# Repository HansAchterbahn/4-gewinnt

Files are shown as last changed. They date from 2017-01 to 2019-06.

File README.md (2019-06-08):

# 4 Gewinnt mit LED Matrix und Raspberry Pi

Das hier liegende Projekt ist ein 4 Gewinnt Spiel. Es funktioniert mit Raspberry Pi und einer LED Matrix. Eine genaue Beschreibung des Projekts findet ihr in dem Ordner *Dokumentaton* oder auf meinem Blog. 
Viel Spaß beim ausprobieren und erweitern!  

Blog:  
https://aetzenloetenprogrammieren.blogspot.de/2016/06/4-gewinnt-auf-led-matrix-mit-raspberry.html

Youtube Video: 4-Gewinnt auf LED-Matrix mit Raspberry Pi (http://www.youtube.com/watch?v=UU7TQ19X6Fk "4-Gewinnt auf LED-Matrix mit Raspberry Pi")

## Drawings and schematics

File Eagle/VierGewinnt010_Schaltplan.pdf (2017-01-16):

GND | GND | GND

# GND

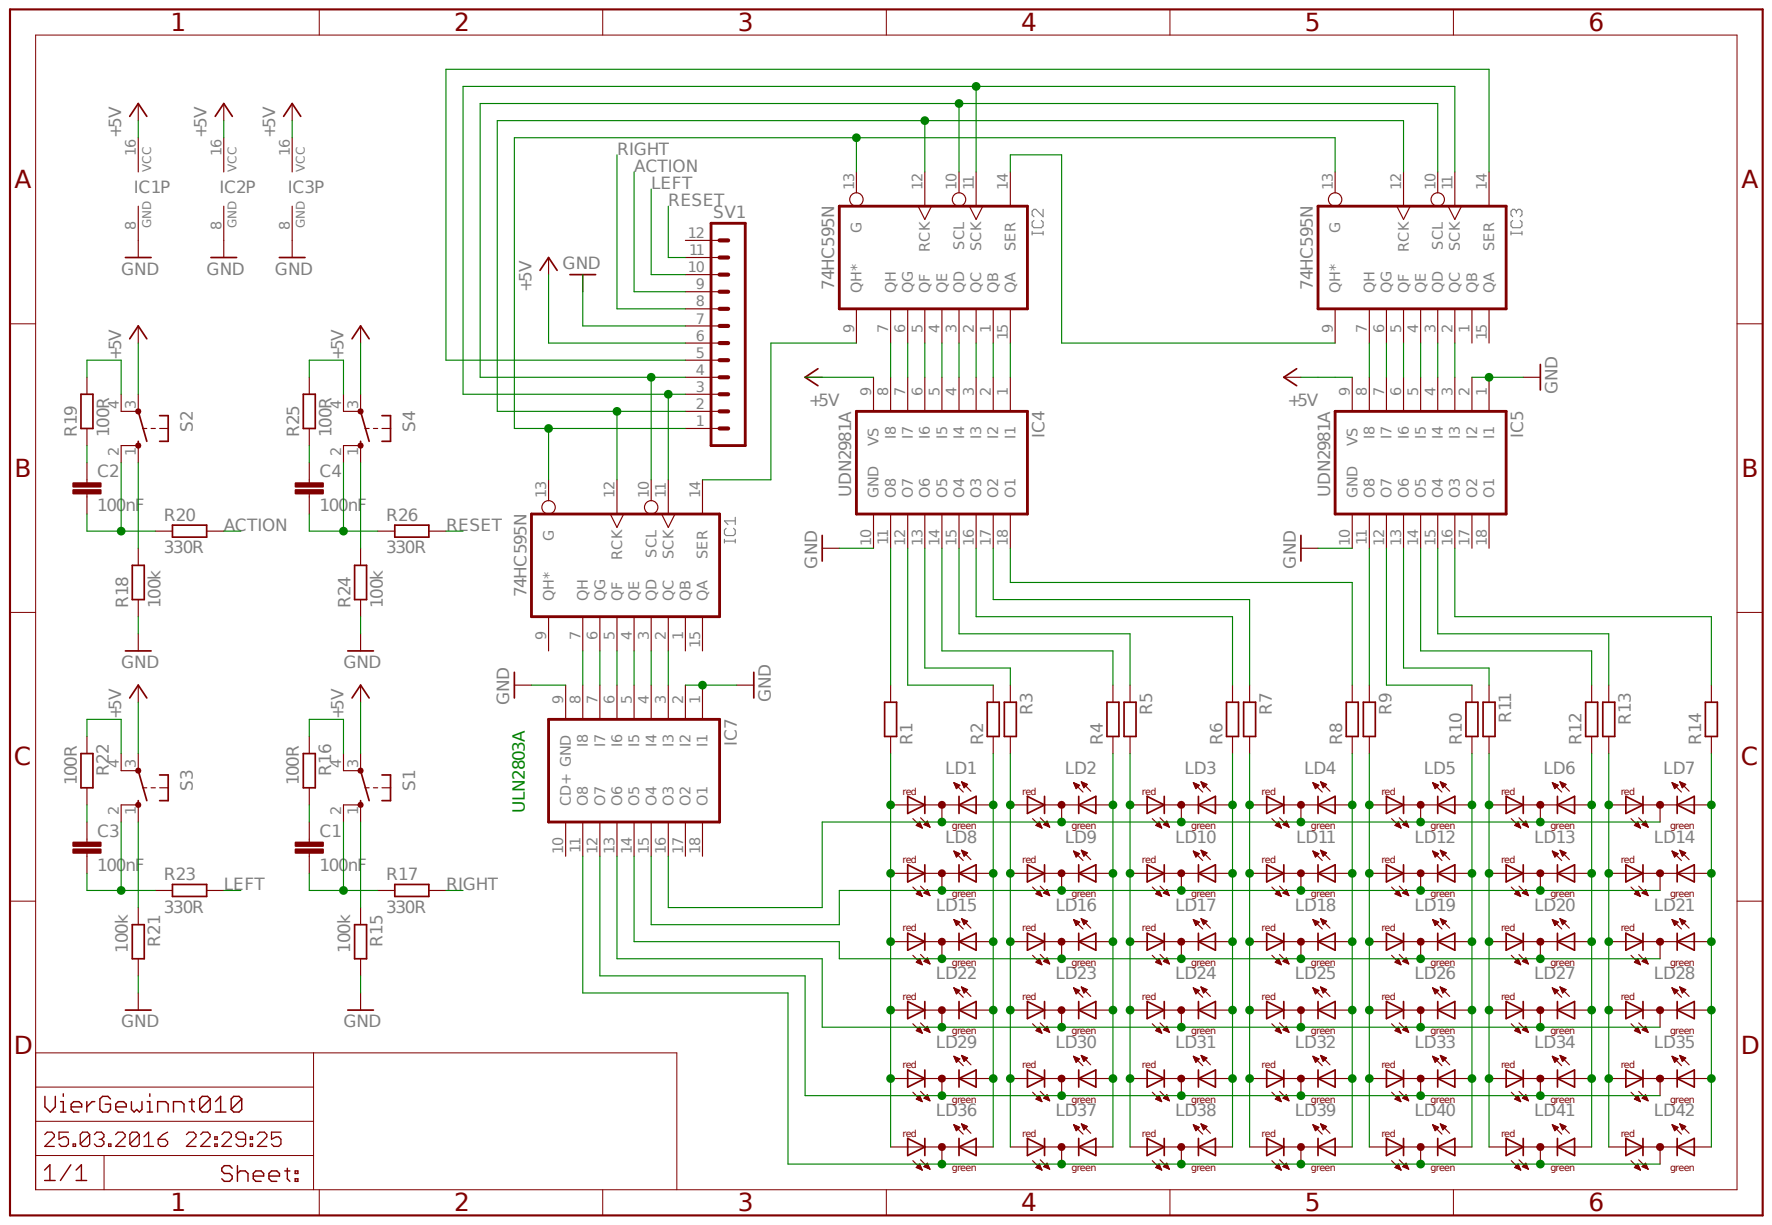
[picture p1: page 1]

QB 1 QC 2 QD 3 QE 4 QF 5 QG 6 QH 7 SCL 10 SCK 11 RCK 12

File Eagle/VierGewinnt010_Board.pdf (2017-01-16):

IC5

# IC7 UDN²⁹⁸¹A UDN²⁹⁸¹A

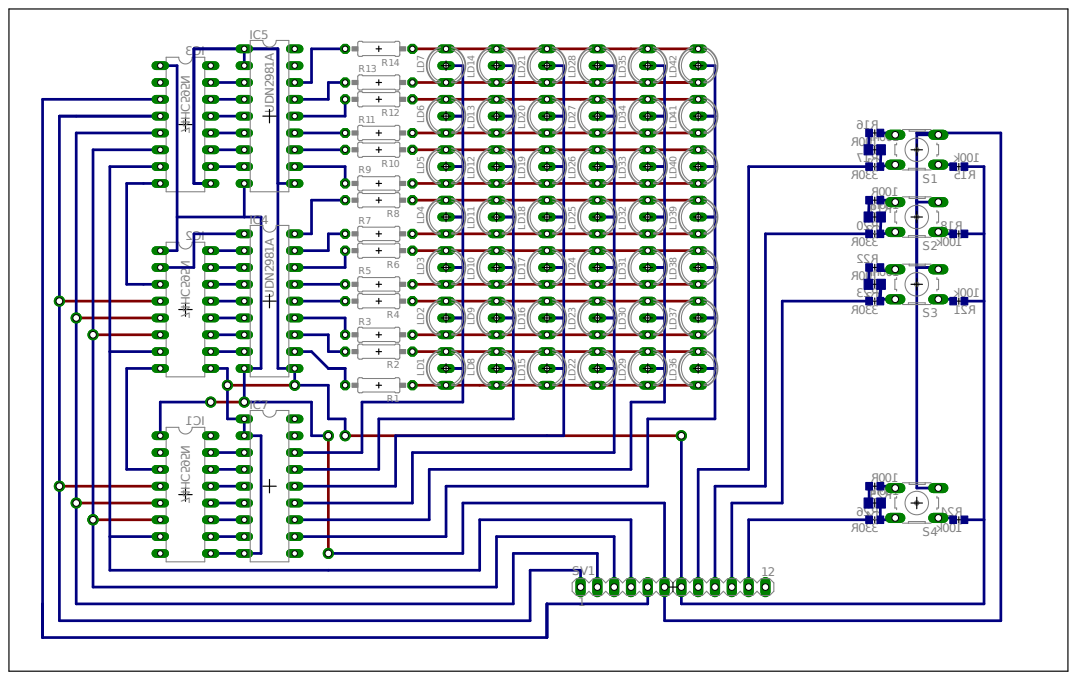
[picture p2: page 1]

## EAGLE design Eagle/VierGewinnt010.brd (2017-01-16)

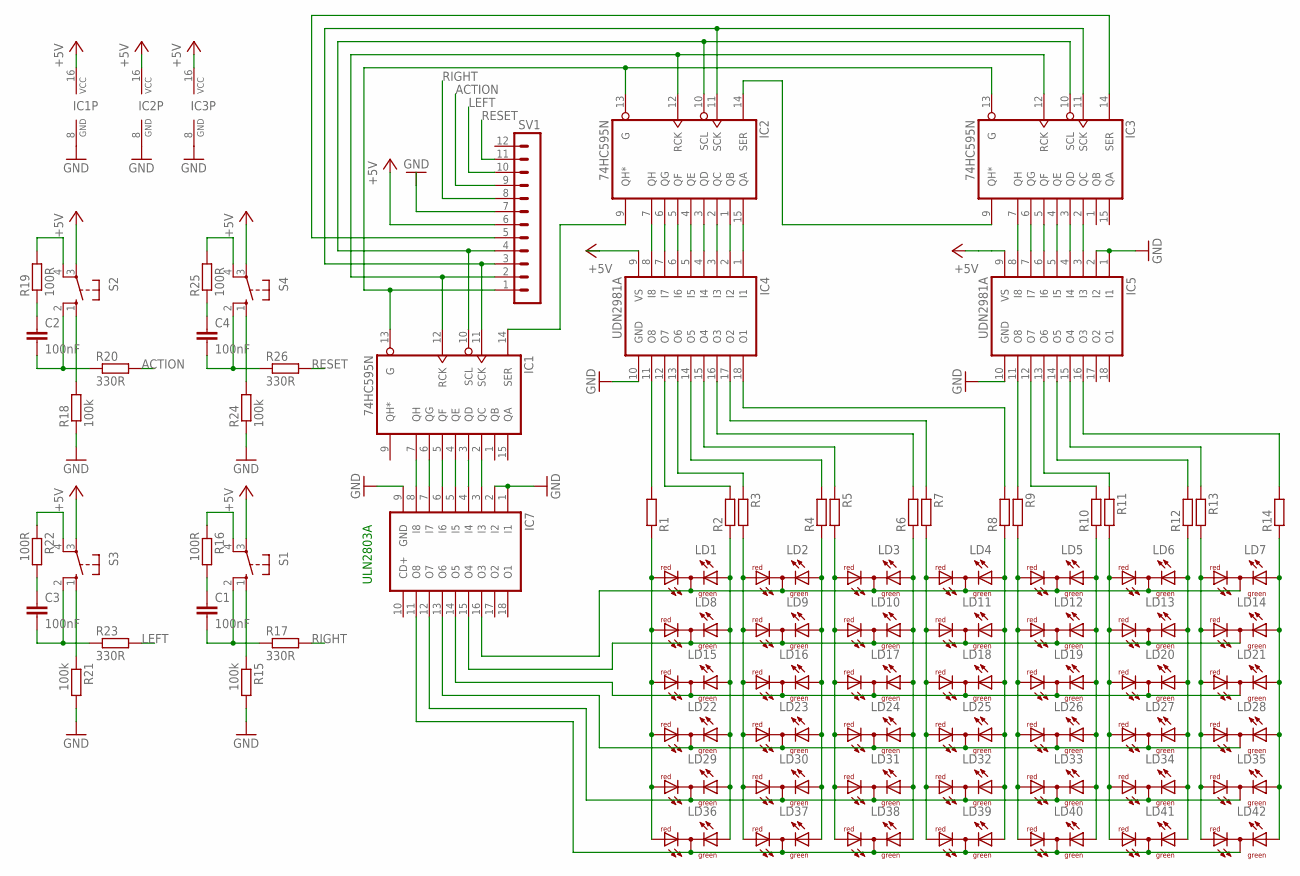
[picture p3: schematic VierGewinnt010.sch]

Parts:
C1, C2, C3, C4: 100nF; C0805
IC1, IC2, IC3: 74HC595N; DIL16
IC4, IC5: UDN2981A; DIL18
IC7: ULN2803A; DIL18
LD1, LD2, LD3, LD4, LD5, LD6, LD7, LD8, LD9, LD10, LD11, LD12, LD13, LD14, LD15, LD16, LD17, LD18, LD19, LD20, LD21, LD22, LD23, LD24, LD25, LD26, LD27, LD28, LD29, LD30, LD31, LD32, LD33, LD34, LD35, LD36, LD37, LD38, LD39, LD40, LD41, LD42: DUOLED-RG-C; DUOLED-C-5MM
R1, R2, R3, R4, R5, R6, R7, R8, R9, R10, R11, R12, R13, R14: R-EU_0207/10; 0207/10
R15, R18, R21, R24: 100k; R0603
R16, R19, R22, R25: 100R; R0603
R17, R20, R23, R26: 330R; R0603
S1, S2, S3, S4: 10-XX; B3F-10XX
SV1: MA12-1

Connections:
+5V: IC1.16 (VCC), IC2.16 (VCC), IC3.16 (VCC), IC4.9 (VS), IC5.9 (VS), S1.3, S2.3, S3.3, S4.3, SV1.6
ACTION: R20.2, SV1.9
GND: IC1.8 (GND), IC2.8 (GND), IC3.8 (GND), IC4.10 (GND), IC5.1 (I1), IC5.2 (I2), IC5.10 (GND), IC7.1 (I1), IC7.2 (I2), IC7.9 (GND), R15.2, R18.1, R21.2, R24.1, SV1.7
LEFT: R23.2, SV1.10
unnamed: LD1.AR, LD8.AR, LD15.AR, LD22.AR, LD29.AR, LD36.AR, R1.1
unnamed: LD1.AX (AG), LD8.AX (AG), LD15.AX (AG), LD22.AX (AG), LD29.AX (AG), LD36.AX (AG), R2.1
unnamed: LD2.AR, LD9.AR, LD16.AR, LD23.AR, LD30.AR, LD37.AR, R3.2
unnamed: LD2.AX (AG), LD9.AX (AG), LD16.AX (AG), LD23.AX (AG), LD30.AX (AG), LD37.AX (AG), R4.1
unnamed: LD3.AR, LD10.AR, LD17.AR, LD24.AR, LD31.AR, LD38.AR, R5.2
unnamed: LD3.AX (AG), LD10.AX (AG), LD17.AX (AG), LD24.AX (AG), LD31.AX (AG), LD38.AX (AG), R6.1
unnamed: LD4.AR, LD11.AR, LD18.AR, LD25.AR, LD32.AR, LD39.AR, R7.2
unnamed: LD4.AX (AG), LD11.AX (AG), LD18.AX (AG), LD25.AX (AG), LD32.AX (AG), LD39.AX (AG), R8.1
unnamed: LD5.AR, LD12.AR, LD19.AR, LD26.AR, LD33.AR, LD40.AR, R9.2
unnamed: LD5.AX (AG), LD12.AX (AG), LD19.AX (AG), LD26.AX (AG), LD33.AX (AG), LD40.AX (AG), R10.1
unnamed: LD6.AR, LD13.AR, LD20.AR, LD27.AR, LD34.AR, LD41.AR, R11.2
unnamed: LD6.AX (AG), LD13.AX (AG), LD20.AX (AG), LD27.AX (AG), LD34.AX (AG), LD41.AX (AG), R12.1
unnamed: LD7.AR, LD14.AR, LD21.AR, LD28.AR, LD35.AR, LD42.AR, R13.2
unnamed: LD7.AX (AG), LD14.AX (AG), LD21.AX (AG), LD28.AX (AG), LD35.AX (AG), LD42.AX (AG), R14.1
unnamed: IC7.16 (O3), LD1.C, LD2.C, LD3.C, LD4.C, LD5.C, LD6.C, LD7.C
unnamed: IC7.14 (O5), LD15.C, LD16.C, LD17.C, LD18.C, LD19.C, LD20.C, LD21.C
unnamed: IC7.13 (O6), LD22.C, LD23.C, LD24.C, LD25.C, LD26.C, LD27.C, LD28.C
unnamed: IC7.12 (O7), LD29.C, LD30.C, LD31.C, LD32.C, LD33.C, LD34.C, LD35.C
unnamed: IC7.11 (O8), LD36.C, LD37.C, LD38.C, LD39.C, LD40.C, LD41.C, LD42.C
unnamed: IC4.11 (O8), R1.2
unnamed: IC4.12 (O7), R2.2
unnamed: IC4.13 (O6), R3.1
unnamed: IC4.14 (O5), R4.2
unnamed: IC4.15 (O4), R5.1
unnamed: IC4.16 (O3), R6.2
unnamed: IC4.17 (O2), R7.1
unnamed: IC4.18 (O1), R8.2
unnamed: IC5.11 (O8), R9.1
unnamed: IC5.12 (O7), R10.2
unnamed: IC5.13 (O6), R11.1
unnamed: IC5.14 (O5), R12.2
unnamed: IC5.15 (O4), R13.1
unnamed: IC5.16 (O3), R14.2
unnamed: IC2.1 (QB), IC4.2 (I2)
unnamed: IC2.2 (QC), IC4.3 (I3)
unnamed: IC2.3 (QD), IC4.4 (I4)
unnamed: IC2.4 (QE), IC4.5 (I5)
unnamed: IC2.5 (QF), IC4.6 (I6)
unnamed: IC2.6 (QG), IC4.7 (I7)
unnamed: IC2.7 (QH), IC4.8 (I8)
unnamed: IC2.15 (QA), IC4.1 (I1)
unnamed: R22.1, S3.4 (P1)
unnamed: IC3.2 (QC), IC5.3 (I3)
unnamed: IC3.3 (QD), IC5.4 (I4)
unnamed: IC3.4 (QE), IC5.5 (I5)
unnamed: IC3.5 (QF), IC5.6 (I6)
unnamed: IC3.6 (QG), IC5.7 (I7)
unnamed: IC3.7 (QH), IC5.8 (I8)
unnamed: C1.1, R16.2
unnamed: IC2.14 (SER), IC3.9 (QH*)
unnamed: IC1.14 (SER), IC2.9 (QH*)
unnamed: IC1.13 (G), IC2.13 (G), IC3.13 (G), SV1.1
unnamed: IC1.12 (RCK), IC2.12 (RCK), IC3.12 (RCK), SV1.2
unnamed: IC1.10 (SCL), IC2.10 (SCL), IC3.10 (SCL), SV1.4
unnamed: IC1.11 (SCK), IC2.11 (SCK), IC3.11 (SCK), SV1.3
unnamed: IC3.14 (SER), SV1.5
unnamed: R18.2, S2.1 (S)
unnamed: R19.2, S2.4 (P1)
unnamed: C1.2, R17.1, S1.2 (S1)
unnamed: R16.1, S1.4 (P1)
unnamed: C3.2, R23.1, S3.2 (S1)
unnamed: C2.2, R20.1, S2.2 (S1)
unnamed: R21.1, S3.1 (S)
unnamed: R15.1, S1.1 (S)
unnamed: C4.1, R25.1
unnamed: R25.2, S4.4 (P1)
unnamed: C2.1, R19.1
unnamed: C4.2, R26.1, S4.2 (S1)
unnamed: C3.1, R22.2
unnamed: R24.2, S4.1 (S)
unnamed: IC1.2 (QC), IC7.3 (I3)
unnamed: IC1.3 (QD), IC7.4 (I4)
unnamed: IC1.4 (QE), IC7.5 (I5)
unnamed: IC1.5 (QF), IC7.6 (I6)
unnamed: IC1.6 (QG), IC7.7 (I7)
unnamed: IC1.7 (QH), IC7.8 (I8)
unnamed: IC7.15 (O4), LD8.C, LD9.C, LD10.C, LD11.C, LD12.C, LD13.C, LD14.C
RESET: R26.2, SV1.11
RIGHT: R17.2, SV1.8

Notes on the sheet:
ULN2803A

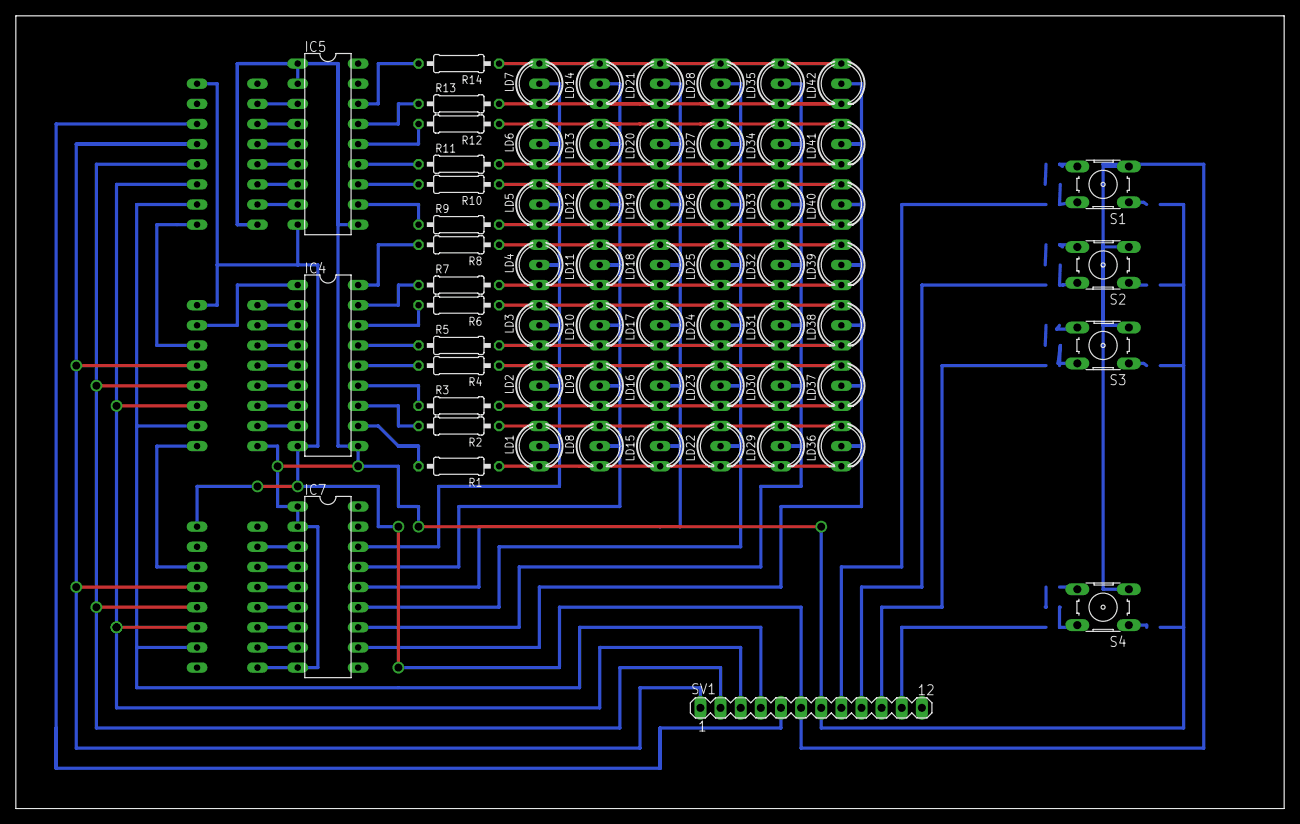
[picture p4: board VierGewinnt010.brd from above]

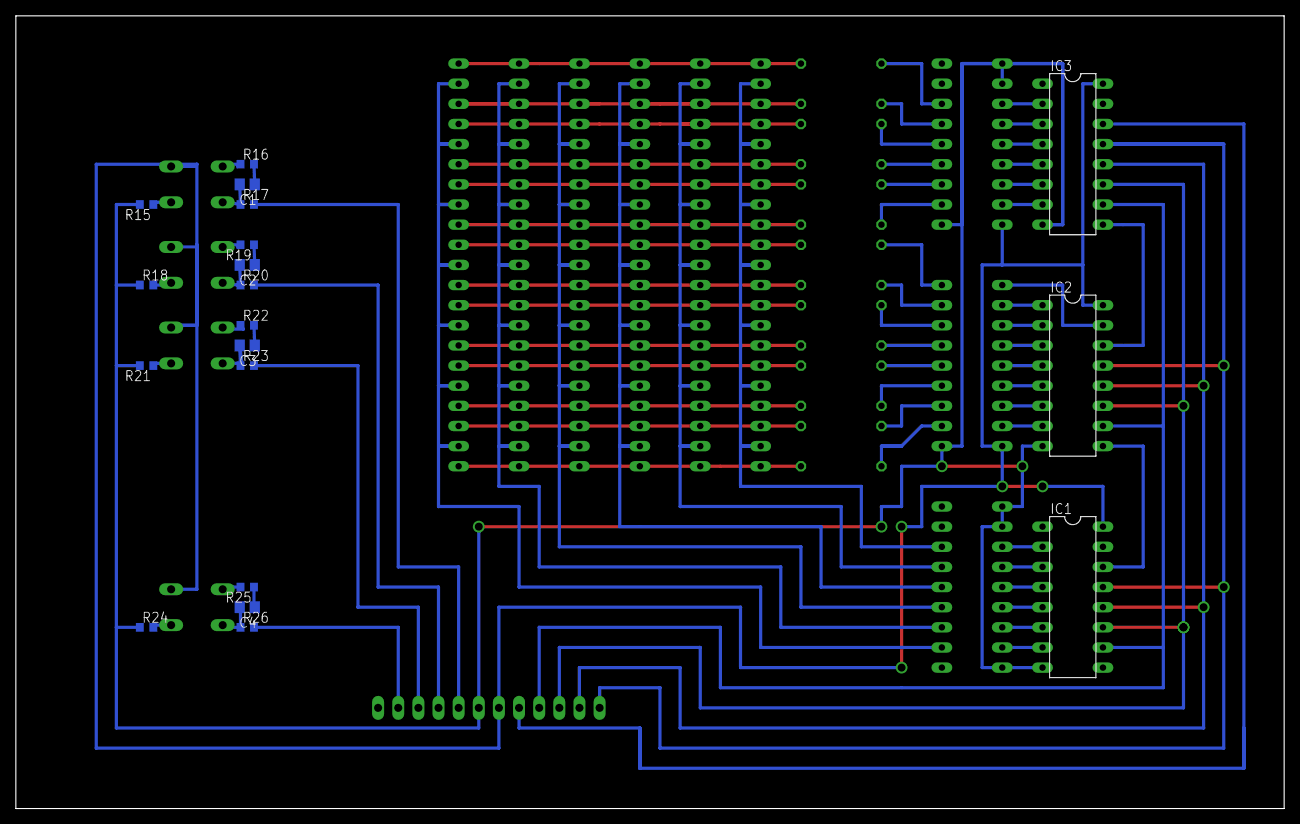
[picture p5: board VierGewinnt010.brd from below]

Board: 2 copper layers, 160.0 x 100.0 mm, 83 parts (19 on the bottom side), 83 nets.

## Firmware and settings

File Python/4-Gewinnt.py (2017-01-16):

### Vier Gewinnt Spiel
### Ansteuerung einer 6x7 LED-Matrix

#------------------------------------------------------------------------#
#                                 HEAD                                   #
#------------------------------------------------------------------------#
### Bibliotheken
import RPi.GPIO as GPIO # Raspberry Pi Standart GPIO Bibliothek
import time             # Bibliothek fuer time-Funktionen
import sys              # This module provides a number of functions and variables that can
                        # be used to manipulate different parts of the Python runtime environment (z.B. sys.exit())

### Initialisierung
GPIO.setmode(GPIO.BCM)  # Verwendung der Pinnamen, wie sie auf dem Board heissen
GPIO.setwarnings(False) # Deaktiviere GPIO-Warnungen
GPIO.cleanup()          # Zuruecksetzen aller GPIO-Pins

G_NOT         = 14      # Output Enable                 OUTPUT
RCK           = 15      # Storage Register Clock        OUTPUT
SCK           = 18      # Shift Register Clock          OUTPUT
SCLR_NOT      = 23      # Shift Register Clear          OUTPUT
SI            = 24      # Serial Data                   OUTPUT
BUTTON_LEFT   = 4       # Button Links                  INPUT
BUTTON_ENTER  = 3       # Button Enter                  INPUT
BUTTON_RIGHT  = 2       # Button Rechts                 INPUT



### Setup GPIOs (Declare GPIOs as INPUT or OUTPUT)
# WICHTIG: Da mit PULL-UP-Widerstand gearbeitet wird, muss der Button den PIN auf LOW ziehen
#          -> Durch Buttondruck wird Pin auf GND gelegt! -> HIGH-Signal in Python
GPIO.setup(G_NOT,GPIO.OUT)                   # OUTPUT
GPIO.setup(RCK,GPIO.OUT)                     # OUTPUT
GPIO.setup(SCK,GPIO.OUT)                     # OUTPUT
GPIO.setup(SCLR_NOT,GPIO.OUT)                # OUTPUT
GPIO.setup(SI,GPIO.OUT)                      # OUTPUT
GPIO.setup(BUTTON_LEFT,GPIO.IN,GPIO.PUD_UP)  # BUTTON_LEFT  -> IN (mit Pull-Up Wiederstand, standartmaessig auf HIGH)
GPIO.setup(BUTTON_ENTER,GPIO.IN,GPIO.PUD_UP) # BUTTON_ENTER -> IN (mit Pull-Up Wiederstand, standartmaessig auf HIGH)
GPIO.setup(BUTTON_RIGHT,GPIO.IN,GPIO.PUD_UP) # BUTTON_RIGHT -> IN (mit Pull-Up Wiederstand, standartmaessig auf HIGH)


### Globale Variablen
# Innerhalb einer Funktion koennen globale Variablen lesend aufgerufen werden
# Will man eine globale Variable innerhalb einer Funktion veraendern,
# muss man diese mit "global ..." in der Funktion definieren!
# Eine innerhalb einer Funktion definierte Variable ist immer lokal
reset               = 0
button_state        = 0                 # Variable fuer Button-Funktion (siehe 'def Button(button_nr)')
button_old          = 0                 # Variable fuer Button-Funktion (siehe 'def Button(button_nr)')
columns             = 14                # 7 Spalten mit jeweils zwei Farben -> 14 (eigentlich 16, da Scheiberegister 16 Bits braucht, letzten 2 Bits sind beliebig und werden in der Funktion send_data() seperat mitgesendet)
columns_unused      = [0,0]             # Anzahl der unbenutzten Spalten (=Anzahl der im Schieberegisterbaustein NICHT benutzten Ausgaenge, HIGH-SIDE)
rows                = 6                 # 6 Zeilen (eigentlich 8, da Schieberegister 8 Bit braucht, letzten 2 Bits sind beliebig und werden in der Funktion send_data() seperat mitgesendet)
rows_unused         = [0,0]             # Anzahl der unbenutzten Zeilen (=Anzahl der im Schieberegisterbaustein nicht benutzten Ausgaenge, LOW-SIDE)
clk_delay           = 0.00000001        # Delay zur sicheren Erkennung der Signalflanken (siehe Datenblatt Schieberegister 74HC595), mind. 6ns
data                = [0]               # Datenvektor mit den aktuellen Daten des Spielfeldes, Initialwert
row                 =  [1,0,0,0,0,0,    # Zeile1
                        0,1,0,0,0,0,    # Zeile2
                        0,0,1,0,0,0,    # Zeile3
                        0,0,0,1,0,0,   	# Zeile4
                        0,0,0,0,1,0,    # Zeile5
                        0,0,0,0,0,1]	# Zeile6
pos                 = 0             	# aktuelle Position in der Matrix (im Datenverktor -> pos = Index des Datenvektors data)
pos_max             = 12            	# maximale Position in einer Zeile (fuer gruen, rot gilt pos_max+1)
player_nr           = 0               	# Player Number (0...Player 1, 1...Player 2)
win_row             = [0,0,0,0]         # Initialwert des Gewinnvekors -> Vektor, der die Positionen der zum Sieg fuehrenden Daten speichert, also Positionen der '4 in einer Reihe'

#------------------------------------------------------------------------#
#                                 Functions                              #
#------------------------------------------------------------------------#
def Button(button_nr):
    #Funktion gibt ein Signal button_state aus, wenn der geforderte Taster gedrueckt wird"
    #Dieses Signal kann nur ausgegeben werden, wenn button_state zuvor 0 war"
    #-> dadurch werden wiederholte Aufrufe der Funktion bei laenger betaetigtem Taster vermieden"
    global button_state
    global button_old

    # Setze button_state auf 1, wenn BUTTON gedrueckt (GPIO.input == 0 wegen Pull-Up) und button_state == 0
    if GPIO.input(button_nr) == 0 and button_state == 0:
        button_old = button_nr                              # Merke aktuelle button_nr
        button_state = 1                                    # Setze button_state auf 1
        time.sleep(0.01)                                    # Zeitverzoegerung, um Tasterprellen zu umgehen
        return button_state                                 # Gib den Wert button_state zurueck

    # Setze button_state auf 0, sobald zuvor betaetigte BUTTON (button_old) losgelassen wird
    elif GPIO.input(button_nr) == 1 and button_state ==1 and button_old == button_nr :
        button_state = 0                                    # Diese elif-Anweisung verhindert, dass der Taster bei durchgehendem Druecken neu ausgeloest wird
        time.sleep(0.01)                                    # Zeitverzoegerung, um Tasterprellen zu umgehen
                                                            # Erfolgt kein Return-Befehlt, liefert die Funktion den Wert 'none'

def Send_Data(data):
    # Funktion sendet 'data' an Shift-Register und aktiviert Ausgabe an das Storage-Register
    # ->Ausgabe der Daten im Storgage-Register auf die LED-Matrix
    # Dabei wird jede Zeile seperat angesteuert
    # -> Immer nur eine Zeile der LED-Matrix wird beschrieben, danach wird diese geloescht und die naechste Zeile beschrieben
    r=0                                 # Zaehlvariable zum Auswaehlen der einzelnen Zeilen im Vektor 'data' und 'row'

    # Schleife sendet (6+2)-Bit-Vektor 'row' mit Information, welche Zeile angesteuert werden soll
    # und (14+2)-Bit-Vektor 'data' mit Information, was in der entsprechenden Zeile angezeigt werden soll
    # (welche LEDs in der entsprechenden Zeile leuchten sollen)
    while r < rows:
        Clear_Shift_Register()                                          # Funktionsaufruf, loesche alle Werte im Shift-Register
        Set_Shift_Register(row[0+r*rows:rows+r*rows])                   # Funktionsaufruf, sende 6-Bit-Vektor 'row' mit Information, welche Zeile angesteuert werden soll
        Set_Shift_Register(rows_unused)                                 # Vektor [0,0] fuer die NICHT benutzten Ausgaenge der Schieberegister HIGH-Side
        Set_Shift_Register(data[0+r*columns:columns+r*columns])         # Funktionsaufruf, sende 14-Bit-Vektor 'data' mit Information, was in der entsprechenden Zeile angezeigt werden soll
        Set_Shift_Register(columns_unused)                              # Vektor [0,0] fuer die NICHT benutzten Ausgaenge der Schieberegister LOW-Side
        Set_Storage_Register()                                          # Funktionsaufruf, Ausgabe der Daten im Shift-Register an LED-Matrix
        r=r+1

def Output_Enable():
    # Funktion aktiviert Ausgaenge der Scheiberegisterbausteine
    GPIO.output(G_NOT,GPIO.LOW)         # Qa bis Qh aktivieren
    time.sleep(clk_delay)               # Delay zur sicheren Erkennung der Signalpegel

def Output_Disable():
    # Funktion deaktiviert Ausgaenge der Scheiberegisterbausteine
    GPIO.output(G_NOT,GPIO.HIGH)        # Qa bis Qh deaktivieren
    time.sleep(clk_delay)               # Delay zur sicheren Erkennung der Signalpegel

def Clear_Shift_Register():
    # Funktion loescht Daten im Shift-Register
    GPIO.output(SCLR_NOT,GPIO.LOW)      # Shift-Register loeschen (solange SCLR_NOT LOW ist)
    time.sleep(clk_delay)
    GPIO.output(SCLR_NOT,GPIO.HIGH)     # Shift-Register wird nichtmehr geloescht
    time.sleep(clk_delay)


def Set_Shift_Register(data):
    # Funktion senden 'data' an Shift-Register
    i=0                                     # Zaehlvariable, Index -> data[i]
    data_length = len(data)                 # Laenge des Datenvektors bestimmen

    while i < data_length:
        # Hier wird geschaut ob das aktuell zu uebergebende Bit 1 oder 0 ist
        if data[i] == 1:
            GPIO.output(SI,GPIO.HIGH)       # Wenn data[i] == 1 -> SERIAL DATA OUTPUT 'SI'auf HIGH
            time.sleep(clk_delay)
        elif data[i] == 0:
            GPIO.output(SI,GPIO.LOW)        # Wenn data[i] == 0 -> SERIAL DATA OUTPUT 'SI' auf LOW
            time.sleep(clk_delay)


        GPIO.output(SCK,GPIO.HIGH)  # Uebergabe des Serial Data Wertes in erste Stufe des Shift-Registers
        time.sleep(clk_delay)       # und Weitergabe der aktuellen Werte des Shiftregisters einer Stufe
        GPIO.output(SCK,GPIO.LOW)   # auf die Naechste bei LOW-HIGH-Flanke
        time.sleep(clk_delay)

        i=i+1


def Set_Storage_Register():
    # Funktion gibt aktuellen Daten im Shift-Register an Storage-Register weiter bei LOW-HIGH-Flanke an RCK
    # (Das Storage-Register (=Ausgang) gibt Daten direkt auf die LED-Matrix bzw. die Treiberstufen vor der Matrix,
    # sofern die Ausgaenge Qa bis Qh der Schieberegisterbausteine aktiviert wurden (siehe 'def Output_Enable()')
    GPIO.output(RCK,GPIO.HIGH)
    time.sleep(clk_delay)
    GPIO.output(RCK,GPIO.LOW)
    time.sleep(clk_delay)


def Sample(sample_nr):
    # Funktion enthaelt verschiedene Samples, welche mithilfe der Funktion Send_Data() auf der LED-Matrix
    # angezeigt werden koennen, z.B.: Send_Data(Sample(2))
    # WICHTIG: Die LED-Matrix besitzt nur 7 LED-Spalten mit je 2 Farben (gruen(g), rot(r)) -> 14 Spalten
    #          Da die Schieberegisterbausteine zur Ansteuerung der Spalten aber 2*8=16 Ausgaenge besitzen,
    #          muessen die 2 ungenutzten Ausgaenge (Spalte 15 und 16) mitgesendet werden
    #          Diese werden in der Funktion send_data() seperat mitgesendet und muessen hier nit extra eingetragen werden

    if sample_nr == 0: 				 # Startbildschirm
            #  |LD1|LD2|LD3|LD4|LD5|LD6|LD7|
            #  |g,r|g,r|g,r|g,r|g,r|g,r|g,r|
        data = [1,0,0,0,0,0,0,0,0,0,0,0,0,0,     # Zeile1
                0,0,0,0,0,0,0,0,0,0,0,0,0,0,     # Zeile2
                0,0,0,0,0,0,0,0,0,0,0,0,0,0,     # Zeile3
                0,0,0,0,0,0,0,0,0,0,0,0,0,0,     # Zeile4
                0,0,0,0,0,0,0,0,0,0,0,0,0,0,     # Zeile5
                0,0,0,0,0,0,0,0,0,0,0,0,0,0]     # Zeile6

    if sample_nr == 1:                           # "HI"
            #  |LD1|LD2|LD3|LD4|LD5|LD6|LD7|
            #  |g,r|g,r|g,r|g,r|g,r|g,r|g,r|
        data = [0,1,0,0,0,0,0,1,0,0,1,0,1,0,     # Zeile1
                0,1,0,0,0,0,0,1,0,0,1,0,1,0,     # Zeile2
                0,1,0,1,0,1,0,1,0,0,1,0,1,0,     # Zeile3
                0,1,0,0,0,0,0,1,0,0,1,0,1,0,     # Zeile4
                0,1,0,0,0,0,0,1,0,0,1,0,1,0,     # Zeile5
                0,1,0,0,0,0,0,1,0,0,1,0,1,0]     # Zeile6

    if sample_nr == 2:                           # "DU"
            #  |LD1|LD2|LD3|LD4|LD5|LD6|LD7|
            #  |g,r|g,r|g,r|g,r|g,r|g,r|g,r|
        data = [1,0,1,0,0,0,0,0,0,1,0,0,0,1,     # Zeile1
                1,0,0,0,1,0,0,0,0,1,0,0,0,1,     # Zeile2
                1,0,0,0,1,0,0,0,0,1,0,0,0,1,     # Zeile3
                1,0,0,0,1,0,0,0,0,1,0,0,0,1,     # Zeile4
                1,0,0,0,1,0,0,0,0,1,0,0,0,1,     # Zeile5
                1,0,1,0,0,0,0,0,0,1,0,1,0,1]     # Zeile6

    if sample_nr == 3:                           # Spieler 1 gewinnt
            #  |LD1|LD2|LD3|LD4|LD5|LD6|LD7|
            #  |g,r|g,r|g,r|g,r|g,r|g,r|g,r|
        data = [1,0,1,0,0,0,0,0,0,0,0,0,1,0,     # Zeile1
                1,0,0,0,1,0,0,0,0,0,1,0,1,0,     # Zeile2
                1,0,1,0,0,0,0,0,1,0,0,0,1,0,     # Zeile3
                1,0,0,0,0,0,0,0,0,0,0,0,1,0,     # Zeile4
                1,0,0,0,0,0,0,0,0,0,0,0,1,0,     # Zeile5
                0,0,0,0,0,0,0,0,0,0,0,0,0,0]     # Zeile6

    if sample_nr == 4:                           # Spieler 2 gewinnt
            #  |LD1|LD2|LD3|LD4|LD5|LD6|LD7|
            #  |g,r|g,r|g,r|g,r|g,r|g,r|g,r|
        data = [0,1,0,1,0,0,0,0,0,1,0,1,0,1,     # Zeile1
                0,1,0,0,0,1,0,0,0,0,0,0,0,1,     # Zeile2
                0,1,0,1,0,0,0,0,0,1,0,1,0,1,     # Zeile3
                0,1,0,0,0,0,0,0,0,1,0,0,0,0,     # Zeile4
                0,1,0,0,0,0,0,0,0,1,0,1,0,1,     # Zeile5
                0,0,0,0,0,0,0,0,0,0,0,0,0,0]     # Zeile6

    if sample_nr == 5: 				 # Unentschieden
            #  |LD1|LD2|LD3|LD4|LD5|LD6|LD7|
            #  |g,r|g,r|g,r|g,r|g,r|g,r|g,r|
        data = [1,0,1,0,1,0,1,0,1,0,1,0,1,0,     # Zeile1
                1,0,0,1,0,1,0,0,0,1,0,1,1,0,     # Zeile2
                1,0,0,0,0,0,0,1,0,0,0,0,1,0,     # Zeile3
                1,0,0,0,0,0,0,1,0,0,0,0,1,0,     # Zeile4
                1,0,0,1,0,1,0,0,0,1,0,1,1,0,     # Zeile5
                1,0,1,0,1,0,1,0,1,0,1,0,1,0]     # Zeile6

    if sample_nr == 6:                           # Lauftext, Player 2 Win
            #  |LD1|LD2|LD3|LD4|LD5|LD6|LD7|  -->                                                                              |LD1|LD2|LD3|LD4|LD5|LD6|LD7|
            #  |g,r|g,r|g,r|g,r|g,r|g,r|g,r|  -->                                                                              |g,r|g,r|g,r|g,r|g,r|g,r|g,r|
        data = [0,0,0,0,0,0,0,0,0,0,0,0,0,0,0,0,0,1,0,1,0,0,0,0,0,1,0,1,0,1,0,0,0,1,0,0,0,0,0,0,0,1,0,0,0,1,0,0,0,1,0,0,0,0,0,1,0,0,0,0,0,0,0,0,0,0,0,0,0,0,     # Zeile1
                0,0,0,0,0,0,0,0,0,0,0,0,0,0,0,0,0,1,0,0,0,1,0,0,0,0,0,0,0,1,0,0,0,1,0,0,0,0,0,0,0,1,0,0,0,1,0,0,0,1,0,0,0,0,0,1,0,0,0,0,0,0,0,0,0,0,0,0,0,0,     # Zeile2
                0,0,0,0,0,0,0,0,0,0,0,0,0,0,0,0,0,1,0,1,0,0,0,0,0,1,0,1,0,1,0,0,0,1,0,0,0,0,0,0,0,1,0,0,0,1,0,0,0,1,0,1,0,0,0,1,0,0,0,0,0,0,0,0,0,0,0,0,0,0,     # Zeile3
                0,0,0,0,0,0,0,0,0,0,0,0,0,0,0,0,0,1,0,0,0,0,0,0,0,1,0,0,0,0,0,0,0,1,0,0,0,1,0,0,0,1,0,0,0,1,0,0,0,1,0,0,0,1,0,1,0,0,0,0,0,0,0,0,0,0,0,0,0,0,     # Zeile4
                0,0,0,0,0,0,0,0,0,0,0,0,0,0,0,0,0,1,0,0,0,0,0,0,0,1,0,1,0,1,0,0,0,0,0,1,0,0,0,1,0,0,0,0,0,1,0,0,0,1,0,0,0,0,0,1,0,0,0,0,0,0,0,0,0,0,0,0,0,0,     # Zeile5
                0,0,0,0,0,0,0,0,0,0,0,0,0,0,0,0,0,0,0,0,0,0,0,0,0,0,0,0,0,0,0,0,0,0,0,0,0,0,0,0,0,0,0,0,0,0,0,0,0,0,0,0,0,0,0,0,0,0,0,0,0,0,0,0,0,0,0,0,0,0]     # Zeile6

    if sample_nr == 7:                           # Lauftext, Start-Screen '4 GEWINNT'
            #  |LD1|LD2|LD3|LD4|LD5|LD6|LD7|  -->     																                                          								   |LD1|LD2|LD3|LD4|LD5|LD6|LD7|
            #  |g,r|g,r|g,r|g,r|g,r|g,r|g,r|  -->                                                                                                                         	                   |g,r|g,r|g,r|g,r|g,r|g,r|g,r|
        data = [0,0,0,0,0,0,0,0,0,0,0,0,0,0,0,0,0,1,0,0,0,1,0,0,0,0,0,1,0,1,0,1,0,1,0,0,0,1,0,1,0,1,0,0,0,1,0,0,0,0,0,0,0,1,0,0,0,1,0,0,0,1,0,0,0,0,0,1,0,0,0,1,0,0,0,0,0,1,0,0,0,1,0,1,0,1,0,1,0,1,0,0,0,0,0,0,0,0,0,0,0,0,0,0,     # Zeile1
                0,0,0,0,0,0,0,0,0,0,0,0,0,0,0,0,0,1,0,0,0,1,0,0,0,0,0,1,0,0,0,0,0,0,0,0,0,1,0,0,0,0,0,0,0,1,0,0,0,0,0,0,0,1,0,0,0,1,0,0,0,1,0,0,0,0,0,1,0,0,0,1,0,0,0,0,0,1,0,0,0,0,0,0,0,1,0,0,0,0,0,0,0,0,0,0,0,0,0,0,0,0,0,0,     # Zeile2
                0,0,0,0,0,0,0,0,0,0,0,0,0,0,0,0,0,1,0,1,0,1,0,0,0,0,0,1,0,0,0,1,0,1,0,0,0,1,0,1,0,1,0,0,0,1,0,0,0,0,0,0,0,1,0,0,0,1,0,0,0,1,0,1,0,0,0,1,0,0,0,1,0,1,0,0,0,1,0,0,0,0,0,0,0,1,0,0,0,0,0,0,0,0,0,0,0,0,0,0,0,0,0,0,     # Zeile3
                0,0,0,0,0,0,0,0,0,0,0,0,0,0,0,0,0,0,0,0,0,1,0,0,0,0,0,1,0,0,0,0,0,1,0,0,0,1,0,0,0,0,0,0,0,1,0,0,0,1,0,0,0,1,0,0,0,1,0,0,0,1,0,0,0,1,0,1,0,0,0,1,0,0,0,1,0,1,0,0,0,0,0,0,0,1,0,0,0,0,0,0,0,0,0,0,0,0,0,0,0,0,0,0,     # Zeile4
                0,0,0,0,0,0,0,0,0,0,0,0,0,0,0,0,0,0,0,0,0,1,0,0,0,0,0,1,0,1,0,1,0,1,0,0,0,1,0,1,0,1,0,0,0,0,0,1,0,0,0,1,0,0,0,0,0,1,0,0,0,1,0,0,0,0,0,1,0,0,0,1,0,0,0,0,0,1,0,0,0,0,0,0,0,1,0,0,0,0,0,0,0,0,0,0,0,0,0,0,0,0,0,0,     # Zeile5
                0,0,0,0,0,0,0,0,0,0,0,0,0,0,0,0,0,0,0,0,0,0,0,0,0,0,0,0,0,0,0,0,0,0,0,0,0,0,0,0,0,0,0,0,0,0,0,0,0,0,0,0,0,0,0,0,0,0,0,0,0,0,0,0,0,0,0,0,0,0,0,0,0,0,0,0,0,0,0,0,0,0,0,0,0,0,0,0,0,0,0,0,0,0,0,0,0,0,0,0,0,0,0,0]     # Zeile6

    return(data)            # Funktion gibt bei Aufruf als Wert den Vektor 'data' zuruek

def Position_Check(level):
    # Funktion zur Ueberpruefung, ob auf der aktuellen Position in der Matrix eine 1 oder eine 0 ist
    # Je nach player_nr wird auch geprueft, ob die rechte oder linke Position der aktuellen 1 oder 0 ist
    # Dies ist wichtig, da sonst in einer LED beide Farben leuchten koennen
    # ->|LD1|
    #   |g,r|
    #   |1,1|
    state = data[pos]==level or (data[pos+1]==level and player_nr==0) or (data[pos-1]==level and player_nr==1)

    return(state)           # Funktion gibt bei Aufruf 'state' (1 oder 0) zuruek

def Win_Check(r):
    # Funktion ueberprueft, ob sich horizontal, vertikal oder diagonal "4 in einer Reihe" befinden
    # Dazu wird ausgehend von der aktuellen Position in allen Richtungen gesucht
    # und die Variable 'coins_in_a_row' hochgezaehlt
    # Sobald diese den Wert 4 erreicht, endet die Funktion und gibt den Wert '1' zurueck
    # Sollten keine 4 in einer Reihe gefunden werden, endet die Funktion ohne Rueckgabewert
    # "4 in einer Reihe" entspricht 4 LEDs der gleichen Farbe in einer Reihe (horizontal, vertikal oder diagonal) auf der LED-Anzeige
    global win_row

    i=1                                         # Zaehlvariable zum aendern der Position horizontal, vertikal oder diagonal
    coins_in_a_row = 1                          # Zaehler fuer Anzahl der LEDs in einer Reihe (horizontal, vertikal oder diagonal)
    r=rows-r-1                                  # r ...in welcher Zeile befinde ich mich aktuell
    x_max = r*columns + pos_max+player_nr       # Abfragegrenze (rechter Rand der Matrix) in x-Richtung
    x_min = r*columns + player_nr               # Abfragegrenze (linkter Rand der Matrix) in x-Richtung
    win_row = [pos,0,0,0]                       # Speichert die Positionen der LEDs in der Gewinn-Reihe (fuer Blinkende Hervorhebung der Gewinnreihe aud Anzeige)


    #Horizontal nach rechts					  			# |0 0 0 0 0 0|
    while pos+i*2<=x_max:								# |0 0 0 0 0 0|
        if data[pos+i*2]==1:							# |0 0 0 0 0 0|
            win_row[coins_in_a_row]=pos+i*2     		# |0 x x x x 0|
            coins_in_a_row=coins_in_a_row+1
            if coins_in_a_row==4:
                return(1)
            i=i+1
        else:
            break
    i=1
    #Horizontal nach links
    while pos-i*2>=x_min:
        if data[pos-i*2]==1:
            win_row[coins_in_a_row]=pos-i*2
            coins_in_a_row=coins_in_a_row+1
            if coins_in_a_row==4:
                return(1)
            i=i+1
        else:
            break


    i=1
    coins_in_a_row=1
    #Vertikal nach unten								# |0 x 0 0 0 0|
    while pos+i*columns<rows*columns:		    		# |0 x 0 0 0 0|
        if data[pos+i*columns]==1:						# |0 x 0 0 0 0|
            win_row[coins_in_a_row]=pos+i*columns   	# |0 x 0 0 0 0|
            coins_in_a_row=coins_in_a_row+1
            if coins_in_a_row==4:
                return(1)
            i=i+1
        else:
            break


    i=1
    coins_in_a_row=1
    #Diagonal nach rechts steigend   			      	# |0 0 0 0 x 0|
    while pos-i*columns>0 and pos+i*2<=x_max:           # |0 0 0 x 0 0|
        if data[pos+i*2-i*columns]==1:                  # |0 0 x 0 0 0|
            win_row[coins_in_a_row]=pos+i*2-i*columns   # |0 x 0 0 0 0|
            coins_in_a_row=coins_in_a_row+1
            if coins_in_a_row==4:
                return(1)
            i=i+1
        else:
            break
    i=1
    #Diagonal nach links fallend
    while pos+i*columns<rows*columns and pos-i*2>=x_min:
        if data[pos-i*2+i*columns]==1:
            win_row[coins_in_a_row]=pos-i*2+i*columns
            coins_in_a_row=coins_in_a_row+1
            if coins_in_a_row==4:
                return(1)
            i=i+1
        else:
            break


    i=1
    coins_in_a_row=1
    #Diagonal nach rechts fallend 										# |0 x 0 0 0 0|
    while pos+i*columns<rows*columns and pos+i*2<=x_max:                # |0 0 x 0 0 0|
        if data[pos+i*2+i*columns]==1:                                  # |0 0 0 x 0 0|
            win_row[coins_in_a_row]=pos+i*2+i*columns                   # |0 0 0 0 x 0|
            coins_in_a_row=coins_in_a_row+1
            if coins_in_a_row==4:
                return(1)
            i=i+1
        else:
            break
    i=1
    #Diagonal nach links steigend
    while pos-i*columns>0 and pos-i*2>=x_min:
        if data[pos-i*2-i*columns]==1:
            win_row[coins_in_a_row]=pos-i*2-i*columns
            coins_in_a_row=coins_in_a_row+1
            if coins_in_a_row==4:
                return(1)
            i=i+1
        else:
            break
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
